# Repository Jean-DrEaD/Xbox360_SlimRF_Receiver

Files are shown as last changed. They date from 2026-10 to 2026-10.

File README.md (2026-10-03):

<p align="center">

  Xbox 360 RF ESP8266

</p>

<p align="center">

  

  

  

  

  

</p>
  
# Xbox 360 RF Module → PC (ESP8266)

Usando módulo RF (**modelo 1409/10 / 1575**) do Xbox 360 Slim(E) como receptor sem fio para controles no PC, via USB.

O **Wemos D1 Mini** controla os LEDs, a animação de boot e o pareamento (Sync). Os dados dos controles passam direto pelo **D+/D-** para o PC.

---

## ✨ Funcionalidades

- 🔆 Inicialização dos LEDs e animação de boot
- 🔗 Pareamento pelo botão Sync físico do módulo
- 🟢 Toque curto: ***Sync***
- 🔴 Segurar 3s: **Desliga** os controles conectados
- ⏱️ Timeout no clock, que evita travar o watchdog do ESP

---
  
## 🧰 Hardware

| Item | Descrição |
| --- | --- |
| Módulo RF | Xbox 360 RF 1410 / 1575 (X864907-004) |
| MCU | Wemos D1 Mini (ESP8266, CH340) |
| Cabo | USB com 4 fios (+5V, D+, D-, GND) |

---

## 🔌 Ligações (Wiring)

<p align="center">

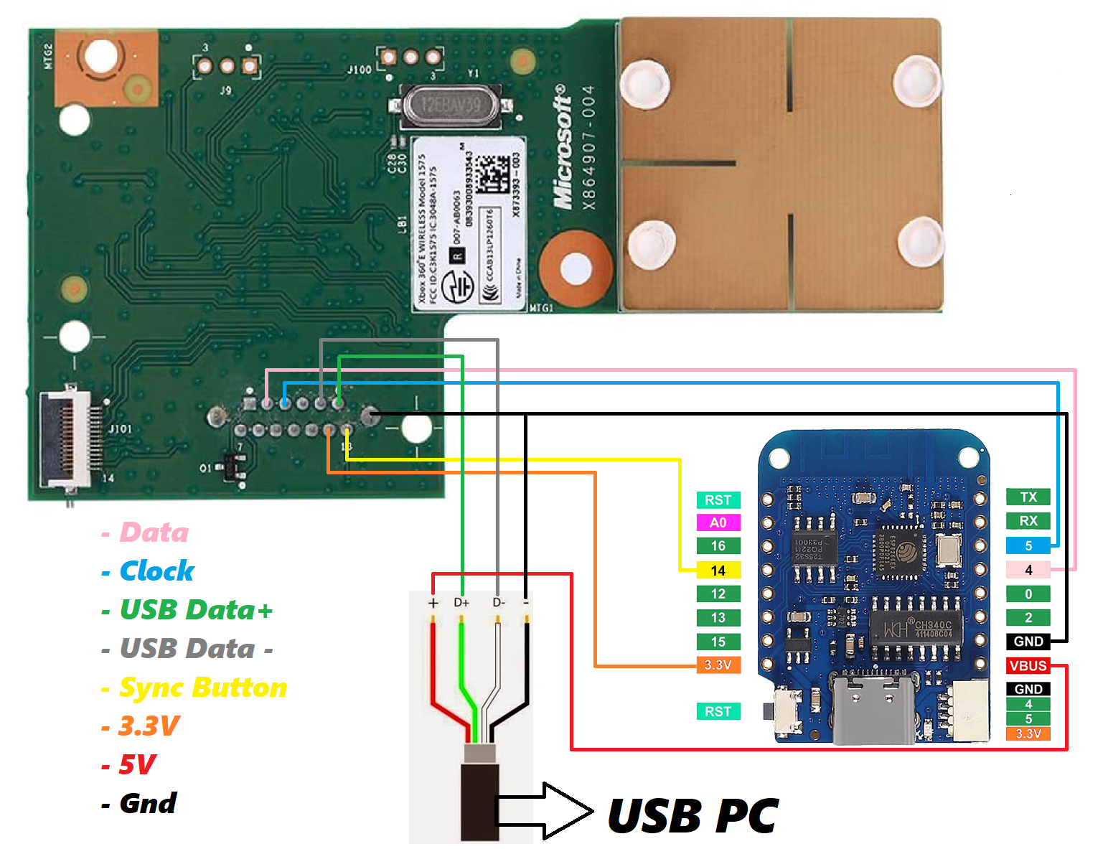
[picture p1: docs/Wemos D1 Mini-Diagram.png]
Wiring Wemos D1 Mini
  

</p>

| Módulo RF | Cor | Destino |
| --- | --- | --- |
| Data | 🩷 Rosa | D2 (GPIO4) |
| Clock | 🔵 Azul | D1 (GPIO5) |
| Sync Button | 🟡 Amarelo  | D5 (GPIO14) |
| 3.3V | 🟠 Laranja  | 3.3V (Wemos) |
| GND | ⚫ Preto | GND (Wemos + USB) |
| USB D+ | 🟢 Verde | D+ do cabo USB |
| USB D- | ⚪ Cinza | D- do cabo USB |
| — | 🔴 Vermelho | +5V do cabo → VBUS do Wemos |
> ⚠️ O módulo RF funciona com **3,3V**. Não ligue o módulo em 5V.

---

## 🚀 Instalação

1. Instale o **core ESP8266** na Arduino IDE.

   - Em *Preferências → URLs adicionais*, adicione:

     `https://arduino.esp8266.com/stable/package_esp8266com_index.json`

2. Selecione a placa **LOLIN(WEMOS) D1 R2 & mini**.

3. Abra `Xbox360_RF_ESP8266.ino` e faça o upload.

4. No Windows, instale o driver **Xbox 360 Wireless Receiver for Windows**.

---
  
## 🛠️ Troubleshooting

- **`TIMEOUT` na Serial:** clock e data podem estar invertidos, ou o módulo está sem 3,3V.

- **Controle não aparece no PC:** verifique o D+/D- e o driver do receptor.

- **LEDs dos quadrantes não respondem:** teste outros códigos com `x<hex>`.

---
## 🙏 Créditos
 
   # **THANKS SKYNET**
 
- [appliedcarbon.org](https://www.appliedcarbon.org/xboxrf.html)

- [dazzaXx/Xbox360RFArduino](https://github.com/dazzaXx/Xbox360RFArduino)

- [AuraudZ/xbox-rf](https://github.com/AuraudZ/xbox-rf)

- [gr33nonline](https://gr33nonline.wordpress.com/2015/09/19/make-an-xbox-receiver/)

- [ginokgx/xbox360slimRF](https://github.com/ginokgx/xbox360slimRF) 

---  

## 📄 Licença

MIT. *Xbox* é marca registrada da Microsoft. Este projeto não é afiliado à Microsoft.

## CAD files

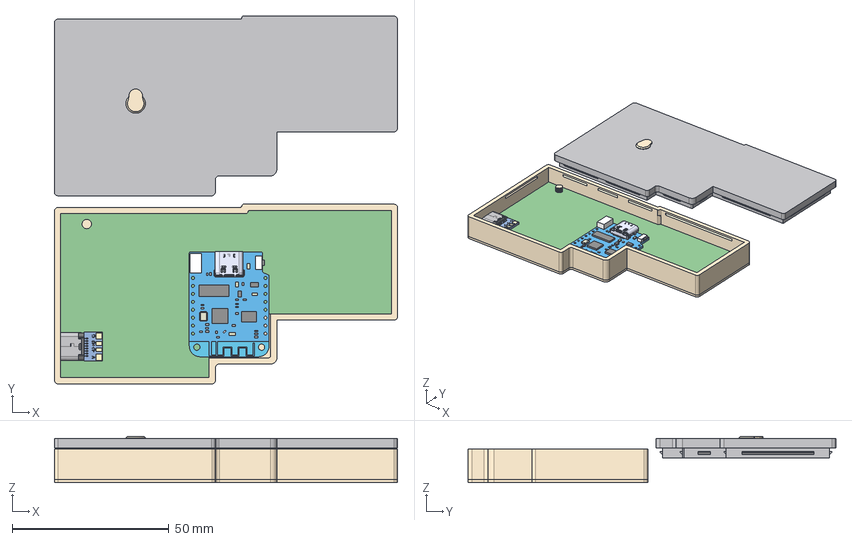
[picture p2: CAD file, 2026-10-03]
case/Case.step
109.5 x 117.4 x 14.7 mm
PCB board
Lid
pins
USB_C_SHELL
USB_C_Body
USB_C_PIN x 16
PCB board_1
text
Contacts
main board

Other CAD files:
case/Case.f3d

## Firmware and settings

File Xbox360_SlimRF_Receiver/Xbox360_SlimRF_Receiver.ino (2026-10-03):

/*
 * Xbox 360 RF Module (1410/1575) -> PC via USB  |  Wemos D1 Mini (ESP8266)
 * Baseado em: appliedcarbon.org, dazzaXx, AuraudZ, gr33nonline, ginokgx
 *
 * Ligacoes (do diagrama):
 *   RF Data  (rosa)    -> GPIO4  (D2)
 *   RF Clock (azul)    -> GPIO5  (D1)
 *   RF Sync  (amarelo) -> GPIO14 (D5)
 *   RF 3.3V  (laranja) -> 3.3V
 *   RF GND             -> GND
 *   RF D+/D-           -> cabo USB do PC (o ESP NAO participa do USB)
 *   VBUS do ESP        -> +5V do cabo USB
 *
 * Funcoes:
 *   - Inicializacao dos LEDs + animacao de boot
 *   - Botao Sync (fisico no modulo) -> modo de pareamento
 *   - Controle de LEDs dos quadrantes (verde/vermelho/laranja)
 *   - Efeitos (spin, blink, erro)
 *   - Comandos pela Serial (115200) para testes
 *   - Timeout no clock (evita travar o watchdog do ESP)
 */

#include <Arduino.h>

#define PIN_DATA   4    // D2
#define PIN_CLOCK  5    // D1
#define PIN_SYNC   14   // D5

#define CLK_TIMEOUT_US 20000UL

// ---------- Comandos do protocolo (10 bits) ----------
#define CMD_LED_INIT     0x084  // 0010000100 - inicializa LEDs
#define CMD_BOOT_ANIM    0x085  // 0010000101 - animacao de boot
#define CMD_SYNC         0x004  // 0000000100 - pareamento
#define CMD_LED_OFF      0x0C0  // 0011000000 - apaga LEDs
#define CMD_GREEN_BASE   0x0A0  // 00101xxxx - verde  (4 bits = quadrantes)
#define CMD_RED_BASE     0x0B0  // 00101 1xxxx - vermelho
#define CMD_CTRL_OFF     0x009  // 0000001001 - desliga controles conectados

// Quadrantes (bits): Q1=0x1 Q2=0x2 Q3=0x4 Q4=0x8
#define Q1 0x1
#define Q2 0x2
#define Q3 0x4
#define Q4 0x8
#define QALL 0xF

bool rfReady = false;
unsigned long lastSyncPress = 0;

// ---------- Baixo nível ----------
bool waitClockChange(int prev) {
  unsigned long t = micros();
  while (digitalRead(PIN_CLOCK) == prev) {
    if (micros() - t > CLK_TIMEOUT_US) return false;
    yield();
  }
  return true;
}

bool sendCmd(uint16_t cmd) {
  noInterrupts();
  pinMode(PIN_DATA, OUTPUT);
  digitalWrite(PIN_DATA, LOW);              // requisita envio
  int prev = digitalRead(PIN_CLOCK);
  bool ok = true;

  for (int i = 9; i >= 0; i--) {            // MSB primeiro
    interrupts();
    if (!waitClockChange(prev)) { ok = false; break; }
    prev = digitalRead(PIN_CLOCK);
    digitalWrite(PIN_DATA, (cmd >> i) & 1); // seta bit na borda
    if (!waitClockChange(prev)) { ok = false; break; }
    prev = digitalRead(PIN_CLOCK);
  }
  interrupts();

  digitalWrite(PIN_DATA, HIGH);
  pinMode(PIN_DATA, INPUT_PULLUP);
  delay(50);

  Serial.printf("CMD 0x%03X -> %s\n", cmd, ok ? "OK" : "TIMEOUT");
  return ok;
}

// ---------- Alto nível ----------
void ledsOff()                 { sendCmd(CMD_LED_OFF); }
void ledsGreen(uint8_t q)      { sendCmd(CMD_GREEN_BASE | (q & 0xF)); }
void ledsRed(uint8_t q)        { sendCmd(CMD_RED_BASE   | (q & 0xF)); }
void ledsOrange(uint8_t q)     { ledsGreen(q); ledsRed(q); }   // verde+vermelho
void syncMode()                { Serial.println("Modo SYNC"); sendCmd(CMD_SYNC); }
void controllersOff()          { sendCmd(CMD_CTRL_OFF); }

void initRF() {
  delay(2000);                              // modulo estabilizar
  rfReady = sendCmd(CMD_LED_INIT);
  delay(100);
  sendCmd(CMD_BOOT_ANIM);
  Serial.println(rfReady ? "RF pronto" : "RF nao respondeu (verifique clock/data)");
}

void effectSpin(uint8_t color, int turns) {           // 0=verde 1=verm 2=laranja
  const uint8_t seq[4] = {Q1, Q2, Q4, Q3};
  for (int t = 0; t < turns; t++)
    for (int i = 0; i < 4; i++) {
      if (color == 0) ledsGreen(seq[i]);
      else if (color == 1) ledsRed(seq[i]);
      else ledsOrange(seq[i]);
      delay(120);
    }
  ledsOff();
}

void effectBlink(uint8_t color, int n) {
  for (int i = 0; i < n; i++) {
    if (color == 0) ledsGreen(QALL); else if (color == 1) ledsRed(QALL); else ledsOrange(QALL);
    delay(250); ledsOff(); delay(250);
  }
}

void effectRRoD() { ledsRed(Q1 | Q2 | Q4); }          // "Red Ring" de brincadeira

// ---------- Botao Sync ----------
void handleSyncButton() {
  if (digitalRead(PIN_SYNC) == LOW && millis() - lastSyncPress > 1000) {
    delay(30);
    if (digitalRead(PIN_SYNC) == LOW) {
      lastSyncPress = millis();
      unsigned long t = millis();
      while (digitalRead(PIN_SYNC) == LOW) yield();
      if (millis() - t > 3000) controllersOff();      // segurar 3s = desliga controles
      else syncMode();
    }
  }
}

// ---------- Serial ----------
void printHelp() {
  Serial.println(F(
    "\nComandos:\n"
    " i  init LEDs + boot\n"
    " s  sync\n"
    " o  apagar LEDs\n"
    " g<hex> verde  (ex: gF, g1)\n"
    " r<hex> vermelho\n"
    " y<hex> laranja\n"
    " p  spin    b  blink    e  RRoD\n"
    " c  desligar controles\n"
    " x<hex> comando bruto 10 bits (ex: x084)\n"
    " h  ajuda"));
}

void handleSerial() {
  if (!Serial.available()) return;
  String l = Serial.readStringUntil('\n'); l.trim();
  if (!l.length()) return;
  char c = l[0];
  uint16_t v = l.length() > 1 ? strtol(l.substring(1).c_str(), NULL, 16) : QALL;
  switch (c) {
    case 'i': initRF(); break;
    case 's': syncMode(); break;
    case 'o': ledsOff(); break;
    case 'g': ledsGreen(v); break;
    case 'r': ledsRed(v); break;
    case 'y': ledsOrange(v); break;
    case 'p': effectSpin(0, 3); break;
    case 'b': effectBlink(2, 3); break;
    case 'e': effectRRoD(); break;
    case 'c': controllersOff(); break;
    case 'x': sendCmd(v & 0x3FF); break;
    default:  printHelp();
  }
}

// ---------- Setup / Loop ----------
void setup() {
  Serial.begin(115200);
  pinMode(PIN_DATA, INPUT_PULLUP);
  pinMode(PIN_CLOCK, INPUT_PULLUP);
  pinMode(PIN_SYNC, INPUT_PULLUP);
  Serial.println("\nXbox 360 RF - ESP8266");
  initRF();
  printHelp();
}

void loop() {
  handleSyncButton();
  handleSerial();
  yield();
}

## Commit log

2026-10-03 Update and 3D Case uploaded
    [Case.f3d, Case.step, Case_Base.step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]
2026-10-03 Update 3D Case file
    [Case.f3d, Case.step, Case_Base.step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]
